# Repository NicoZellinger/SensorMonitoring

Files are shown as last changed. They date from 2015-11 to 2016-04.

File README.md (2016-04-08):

#Universal Data Aquisition Network System

#SensorMonitoring
In this project a system should be developed which is possible to carry out several sensor measurements and to send the values over WLAN to a central system. 
Afterwards in the central system the measuring results should be evaluated and documented for a period. 

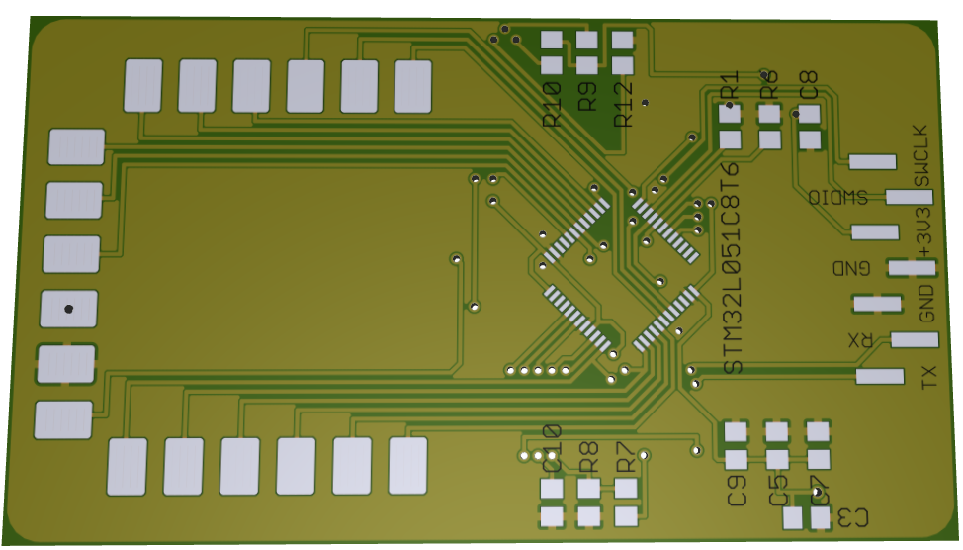
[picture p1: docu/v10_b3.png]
Bottom

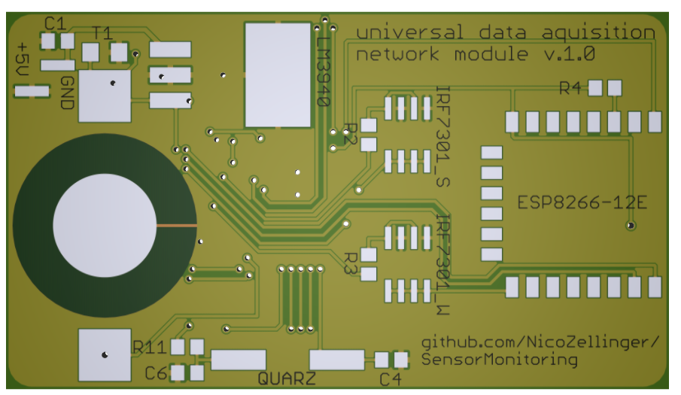
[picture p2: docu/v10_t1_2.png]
top


# Hardware
In the essentials the sensor board is a WLAN module, a microcontroller and any sensor. 
The microcontroller reads the values of the sensor in a configureable frequency and transfers this to the WLAN module. 
The WLAN module sends the values to the central system (Raspberry Pi with Raspbian). 
Afterwards on the central system the measuring results are evaluated and documented. 
Beyond it, the central system administered the sensor boards. 

# Power
So that the sensor boards can be used mobile, the boards are supplied with a 3 volt battery. 
To put off the unloading of the battery as long as possible a "ultra low power" microcontroller from STMicroelectronic is used.
Besides, the controller is moved, as long as he takes up no measurement, into the Sleep mode. 
Above, the WLAN module and the sensor is separated with the help of a FET from the supply voltage (As long as no measurement is made).

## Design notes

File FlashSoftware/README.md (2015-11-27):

## This is the Software to generate the *.hex* file for sensorboard with breakout

## Idea
The software should have a button to load the *.hex* file containing the firmware to flash.  
For every generated firmware there should be an JSON file describing the variables one
can edit in the flash storage.

In the software, one loads the *.hex* file containing the firmware and the JSON file.
With the JSON file the software can present a list of variables the user can edit.  
Then the user can click a *save* button to generate a new *.hex* file with the firmware
and the variables.  
This file can now be flashed.

## UI design
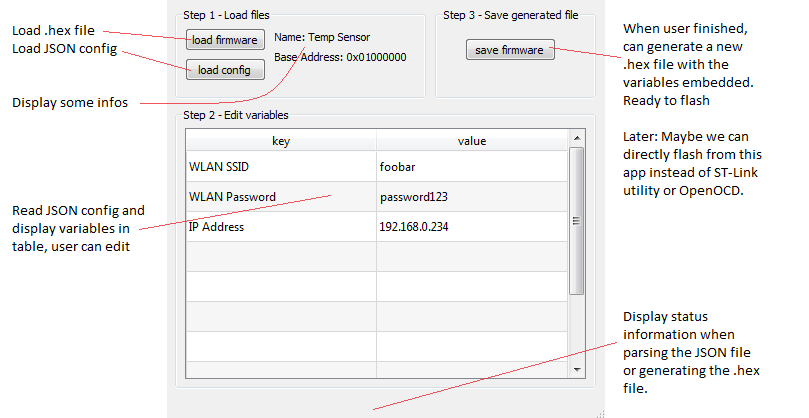
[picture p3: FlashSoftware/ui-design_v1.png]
UI design


### Description
Every variable has a id (the variable name in the firmware), an real name, a type to do typechecking when user edits
and an offset to the base address where this variable is written in the *.hex* file or flash.

Would be nice in the future to generate the JSON file out of the sourcecode directly.  
This could be achieved by marking a section with the variables with code comments.  
The offset can be calculated with the pointer address. The name can be specified by comment and the
type can be obtained out of the code.

## SPEC
Here is an example for the JSON files which describe the variables one can edit:  
[http://www.jsoneditoronline.org/?id=5f7bb21513ac1fcfc43e39b30b590ad5](http://www.jsoneditoronline.org/?id=5f7bb21513ac1fcfc43e39b30b590ad5)

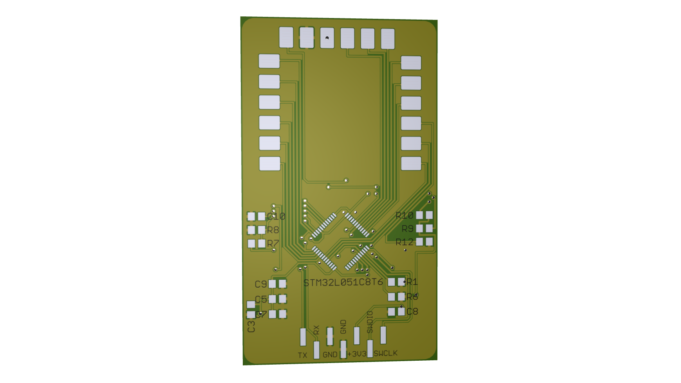
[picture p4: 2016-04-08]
docu/v10_b2.png

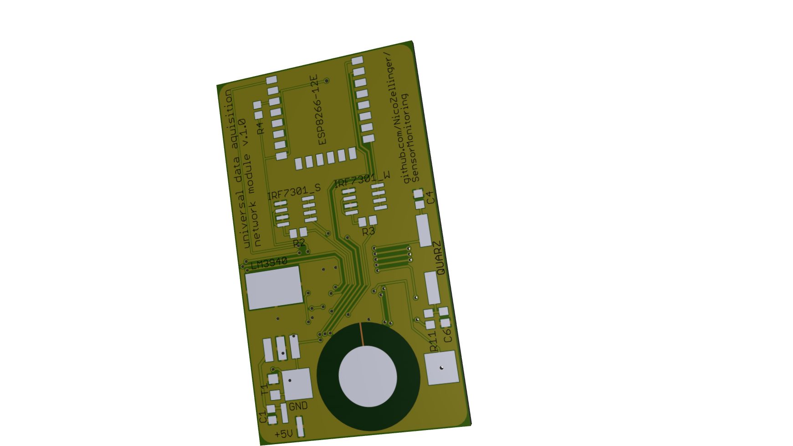
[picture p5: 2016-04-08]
docu/v10_t3.png

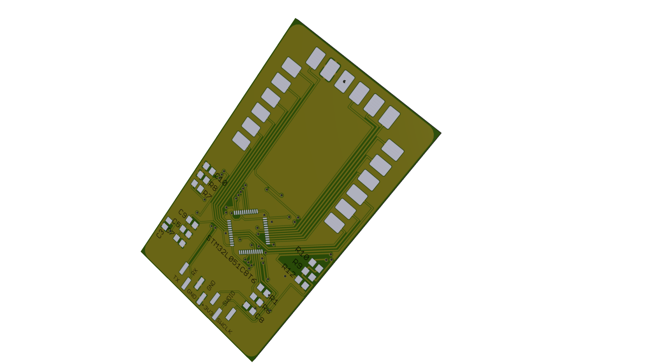
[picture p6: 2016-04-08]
docu/v10_b1.png

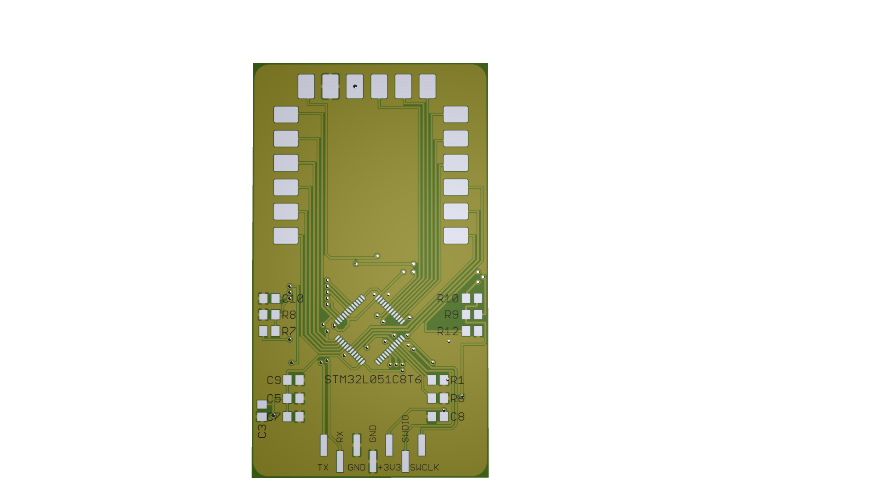
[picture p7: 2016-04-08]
docu/v10_b5.png

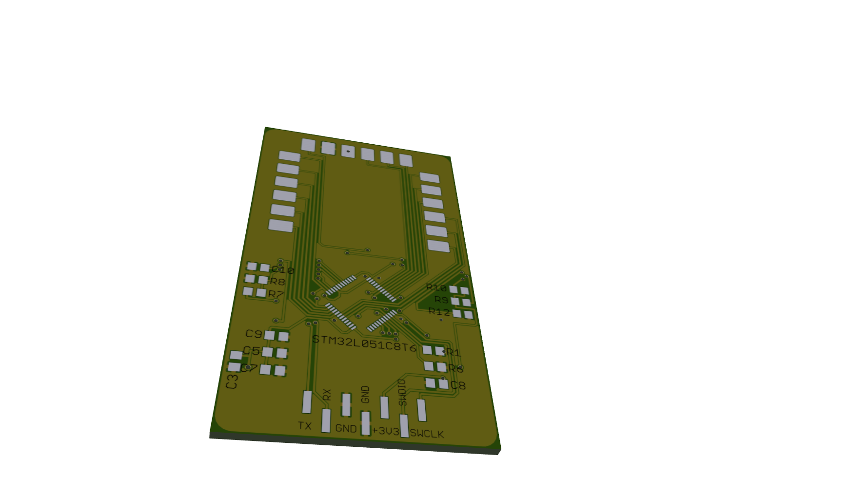
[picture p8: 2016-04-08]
docu/v10_b4.png

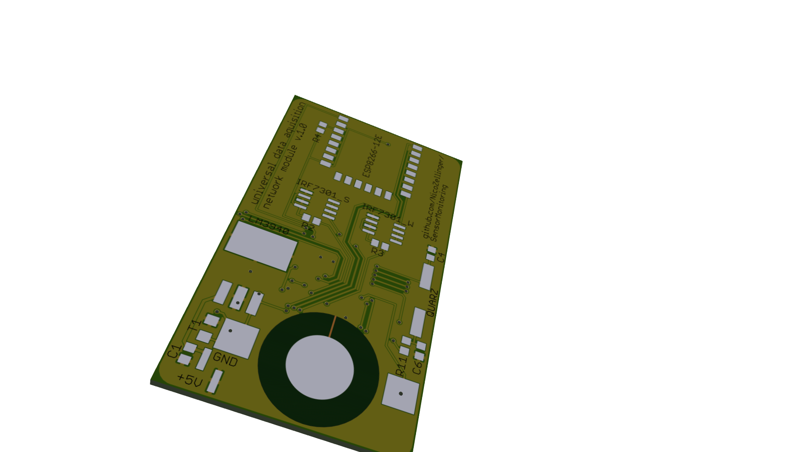
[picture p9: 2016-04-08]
docu/v10_t2.png

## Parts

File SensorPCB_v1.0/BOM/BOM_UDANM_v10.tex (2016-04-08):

\documentclass[a4paper,fontsize=12pt,fleqn]{scrartcl}
\usepackage[ngerman]{babel}
\usepackage[utf8]{inputenc}												
\usepackage[automark]{scrpage2}

\usepackage[hyphens]{url}
\usepackage{hyperref}
\usepackage{amsmath}
\hypersetup{unicode=true,colorlinks=true,urlcolor=black,citecolor=black,linkcolor=black}

\usepackage{caption}
\captionsetup[figure]{skip=10pt}

\usepackage{array}
\usepackage{multirow}
\usepackage{subfigure} 
\usepackage{tabularx}
\newcolumntype{L}[1]{>{\raggedright\arraybackslash}p{#1}}
\newcolumntype{C}[1]{>{\centering\arraybackslash}p{#1}}
\newcolumntype{R}[1]{>{\raggedleft\arraybackslash}p{#1}}

\pagestyle{scrheadings}
\renewcommand*{\sectionmarkformat}{}
\clearscrheadfoot{}
\setkomafont{pagenumber}{\bfseries}
\ohead[]{Bill of Materials}
 \cfoot{\raisebox{-4.5mm}{-{ }\pagemark{ }-}} 
\usepackage{anyfontsize}
\usepackage{geometry}
\geometry{a4paper, top=27mm, left=25mm, right=20mm, bottom=35mm, headsep=10mm, footskip=20mm}
\usepackage{setspace} 
\onehalfspacing

\begin{document}

\pagenumbering{arabic}
\setcounter{page}{1}
%
\input{source/BOM}

\end{document}

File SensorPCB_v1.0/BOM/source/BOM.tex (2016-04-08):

\section*{Bill of Materials}

\begin{table}[h] \centering
    \begin{tabular}{|c|c|c|c|c|}\hline
    \textbf{Name}        &\textbf{Value}    & \textbf{Quantity}	    & \textbf{Package}    & \textbf{Links}\\ \hline
%
     C1    			     & 470n            & 1			            & 0805                & \url{?}\\ \hline
     C3    			     & 10u             & 1			            & 0805                & \url{}\\ \hline
     C4, C6    		     & 20p             & 2			            & 0805                & \url{}\\ \hline
     C5, C7, C8, C10     & 100n            & 1			            & 0805                & \url{}\\ \hline
     C9    			     & 1u              & 1			            & 0805                & \url{}\\ \hline
     ESP8266-12E (WLAN)  & ESP8266-12E     & 1			            & ESP8266-12E         & \url{ebay.de}\\ \hline
     IRF7301\_S/W        & NPN             & 2			            & SO8                 & \url{}\\ \hline
     JP1, PHD (Pinheader)&                 & 9			            & SMD, 2.54 mm        & \url{}\\ \hline
     LM3940    			 & 5V to 3.3V      & 1			            & DDPACK              & \url{}\\ \hline
     QUARZ    			 & 8 MHz           & 1			            & HC49-SMD            & \url{}\\ \hline
     R1, R6    		     & 100k            & 2			            & 0805                & \url{}\\ \hline
     R2, R3    			 & 150             & 2		                & 0805                & \url{}\\ \hline
     R4, R7, R8, R12     & 10k             & 4	                    & 0805                & \url{}\\ \hline
     R9, R10    	     & 1.8k            & 2			            & 0805                & \url{}\\ \hline
     R11  			     & 390             & 1			            & 0805                & \url{}\\ \hline
     STM32L051C8T6       &                 & 1			            & LQFP48              & \url{}\\ \hline
     T1    			     & 33u Tantal      & 1			            & 1206                & \url{}\\ \hline
     KZH\_20SMD (Battery)&                 & 1			            & KZH\_20SMD          & \url{}\\ \hline
 \end{tabular}
 \caption{BOM SensorPCB Version 1.0}
 \label{tab:plat}
\end{table}

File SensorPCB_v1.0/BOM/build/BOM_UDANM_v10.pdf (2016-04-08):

Bill of Materials

## Bill of Materials

Name | Value | Quantity | Package | Links
C1 | 470n | 1 | 0805 | ?
C3 | 10u | 1 | 0805
C4, C6 | 20p | 2 | 0805
C5, C7, C8, C10 | 100n | 1 | 0805
C9 | 1u | 1 | 0805
ESP8266-12E (WLAN) | ESP8266-12E | 1 | ESP8266-12E | ebay.de
IRF7301 S/W | NPN | 2 | SO8
JP1, PHD (Pinheader) | | 9 | SMD, 2.54 mm
LM3940 | 5V to 3.3V | 1 | DDPACK
QUARZ | 8 MHz | 1 | HC49-SMD
R1, R6 | 100k | 2 | 0805
R2, R3 | 150 | 2 | 0805
R4, R7, R8, R12 | 10k | 4 | 0805
R9, R10 | 1.8k | 2 | 0805
R11 | 390 | 1 | 0805
STM32L051C8T6 | | 1 | LQFP48
T1 | 33u Tantal | 1 | 1206
KZH 20SMD (Battery) | | 1 | KZH 20SMD

Tabelle 1: BOM SensorPCB Version 1.0

- 1 -

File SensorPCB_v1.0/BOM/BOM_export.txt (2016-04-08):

Partlist

Exported from SensorPCB.sch at 12.12.15 22:51

EAGLE Version 7.4.0 Copyright (c) 1988-2015 CadSoft

Assembly variant: 

Part          Value          Device                    Package               Library               Sheet

BREAKOUTBOARD BREAKOUT_FP_V1 BREAKOUT_FP_V1            BREAKOUT_FOOTPRINT_V1 breakout_base         1
C1            470n           C-EUC0805                 C0805                 rcl                   1
C3            10u            C-EUC0805                 C0805                 rcl                   1
C4            20p            C-EUC0805                 C0805                 rcl                   1
C5            100n           C-EUC0805                 C0805                 rcl                   1
C6            20p            C-EUC0805                 C0805                 rcl                   1
C7            100n           C-EUC0805                 C0805                 rcl                   1
C8            100n           C-EUC0805                 C0805                 rcl                   1
C9            1u             C-EUC0805                 C0805                 rcl                   1
C10           100n           C-EUC0805                 C0805                 rcl                   1
ESP8266-12E                  ESP8266-12EESP8266-ESP12E ESP8266-ESP12E        ESP8266-ESP12E        1
IRF7301_S     IRF7301        IRF7301                   IRF7301_PACK_SO8      irf7301_symb          1
IRF7301_W     IRF7301        IRF7301                   IRF7301_PACK_SO8      irf7301_symb          1
JP1                          PINHD-1X2_2.54-SMD        1X02SMD               pinhead               1
LM3940        LM3940         LM3940                    LM3940_PACK           lm3940                1
PHD                          PINHD-1X7_2.54-SMD        1X07SMD               pinhead               1
QUARZ         QUARZ_HC49-SMD QUARZ_HC49-SMD            HC49-SMD              quarz_hc49_smd        1
R1            100k           R-EU_R0805                R0805                 rcl                   1
R2            150            R-EU_R0805                R0805                 rcl                   1
R3            150            R-EU_R0805                R0805                 rcl                   1
R4            10k            R-EU_R0805                R0805                 rcl                   1
R6            100k           R-EU_R0805                R0805                 rcl                   1
R7            10k            R-EU_R0805                R0805                 rcl                   1
R8            10k            R-EU_R0805                R0805                 rcl                   1
R9            1k8            R-EU_R0805                R0805                 rcl                   1
R10           1k8            R-EU_R0805                R0805                 rcl                   1
R11           390            R-EU_R0805                R0805                 rcl                   1
R12           10k            R-EU_R0805                R0805                 rcl                   1
STM32L051C8T6 STM32L051X6/8  STM32L051X6/8             LQFP48                STM32L051x6_LQFP48XXL 1
T1            33u            CAP_TANTAL_1206           1206                  CAP_TANTAL_1206       1
U$1           KZH_20SMD      KZH_20SMD                 KHZ_20SMD             KZH_20SMD             1

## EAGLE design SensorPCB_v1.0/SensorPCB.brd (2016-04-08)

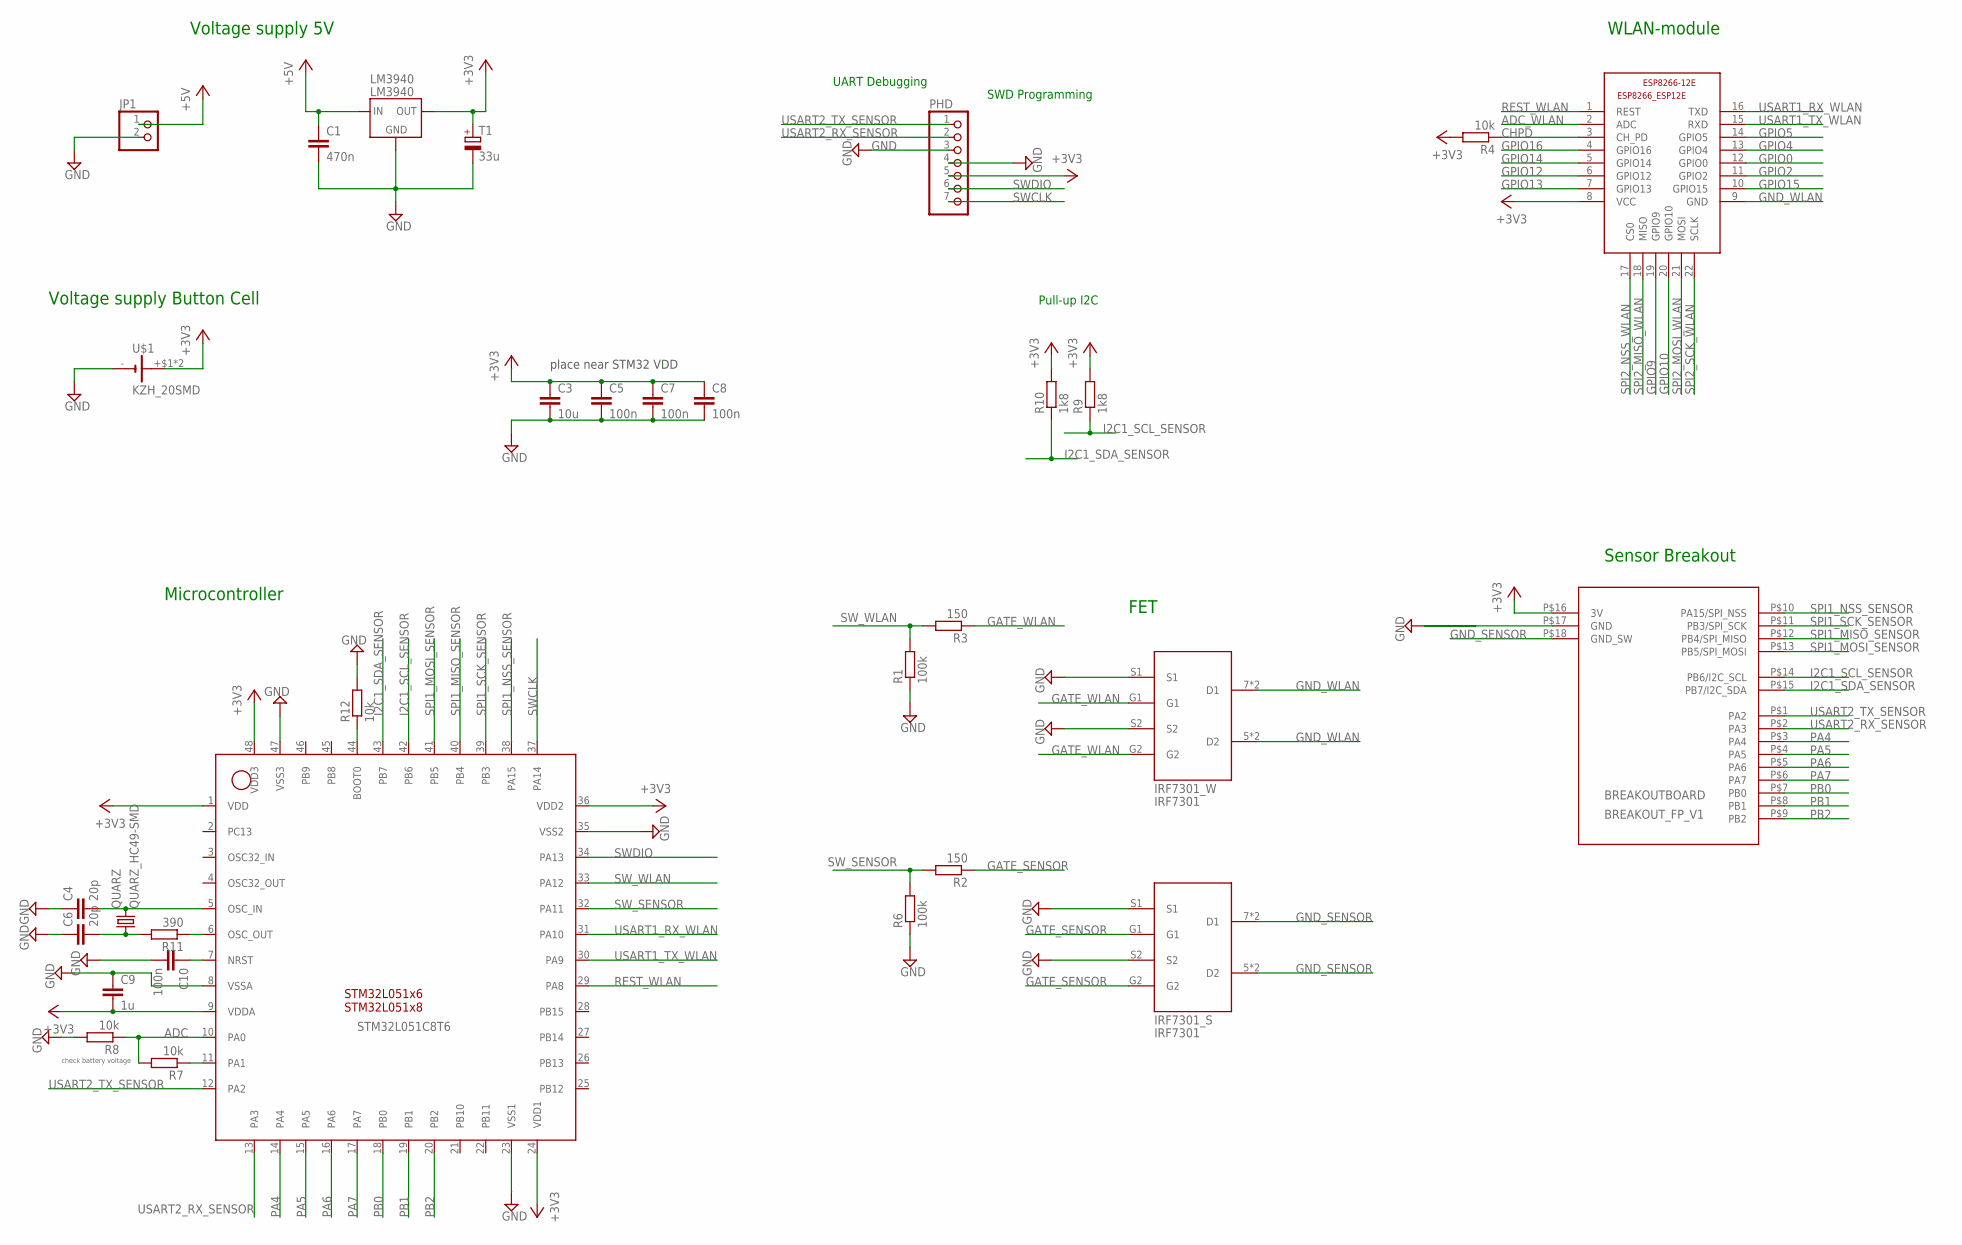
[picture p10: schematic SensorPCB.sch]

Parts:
BREAKOUTBOARD: BREAKOUT_FP_V1; BREAKOUT_FOOTPRINT_V1
C1: 470n; C0805
C3: 10u; C0805
C4, C6: 20p; C0805
C5, C7, C8, C10: 100n; C0805
C9: 1u; C0805
ESP8266-12E: ESP8266-12EESP8266-ESP12E; ESP8266-ESP12E
IRF7301_S, IRF7301_W: IRF7301; IRF7301_PACK_SO8
JP1: PINHD-1X2_2.54-SMD; 1X02SMD
LM3940: LM3940; LM3940_PACK
PHD: PINHD-1X7_2.54-SMD; 1X07SMD
QUARZ: QUARZ_HC49-SMD; HC49-SMD
R1, R6: 100k; R0805
R2, R3: 150; R0805
R4, R7, R8, R12: 10k; R0805
R9, R10: 1k8; R0805
R11: 390; R0805
STM32L051C8T6: STM32L051X6/8; LQFP48
T1: 33u; 1206
U$1: KZH_20SMD; KHZ_20SMD

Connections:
+3V3: BREAKOUTBOARD.P$16 (3V), C3.1, C5.1, C7.1, C8.1, C9.2, ESP8266-12E.8 (VCC), LM3940.3 (OUT), PHD.5, R4.2, R9.2, R10.2, STM32L051C8T6.1 (VDD), STM32L051C8T6.9 (VDDA), STM32L051C8T6.24 (VDD1), STM32L051C8T6.36 (VDD2), STM32L051C8T6.48 (VDD3), T1.1 (+), U$1.+$1 (+), U$1.+$2 (+)
+5V: C1.1, JP1.1, LM3940.1 (IN)
ADC: R7.2, R8.1, STM32L051C8T6.10 (PA0)
ADC_WLAN: ESP8266-12E.2 (ADC)
CHPD: ESP8266-12E.3 (CH_PD), R4.1
GATE_SENSOR: IRF7301_S.G1, IRF7301_S.G2, R2.1
GATE_WLAN: IRF7301_W.G1, IRF7301_W.G2, R3.1
GND: BREAKOUTBOARD.P$17 (GND), C1.2, C3.2, C4.1, C5.2, C6.1, C7.2, C8.2, C9.1, C10.2, IRF7301_S.S1, IRF7301_S.S2, IRF7301_W.S1, IRF7301_W.S2, JP1.2, LM3940.2 (GND), LM3940.4 (GND), PHD.3, PHD.4, R1.1, R6.1, R8.2, R12.2, STM32L051C8T6.8 (VSSA), STM32L051C8T6.23 (VSS1), STM32L051C8T6.35 (VSS2), STM32L051C8T6.47 (VSS3), T1.2 (-), U$1.-
GND_SENSOR: BREAKOUTBOARD.P$18 (GND_SW), IRF7301_S.5 (D2), IRF7301_S.7 (D1), IRF7301_S.D1, IRF7301_S.D2
GND_WLAN: ESP8266-12E.9 (GND), IRF7301_W.5 (D2), IRF7301_W.7 (D1), IRF7301_W.D1, IRF7301_W.D2
GPIO0: ESP8266-12E.12 (GPIO0)
GPIO2: ESP8266-12E.11 (GPIO2)
GPIO4: ESP8266-12E.13 (GPIO4)
GPIO5: ESP8266-12E.14 (GPIO5)
GPIO9: ESP8266-12E.19 (GPIO9)
GPIO10: ESP8266-12E.20 (GPIO10)
GPIO12: ESP8266-12E.6 (GPIO12)
GPIO13: ESP8266-12E.7 (GPIO13)
GPIO14: ESP8266-12E.5 (GPIO14)
GPIO15: ESP8266-12E.10 (GPIO15)
GPIO16: ESP8266-12E.4 (GPIO16)
I2C1_SCL_SENSOR: BREAKOUTBOARD.P$14 (PB6/I2C_SCL), R9.1, STM32L051C8T6.42 (PB6)
I2C1_SDA_SENSOR: BREAKOUTBOARD.P$15 (PB7/I2C_SDA), R10.1, STM32L051C8T6.43 (PB7)
unnamed: R7.1, STM32L051C8T6.11 (PA1)
unnamed: C6.2, QUARZ.1, R11.2
unnamed: C10.1, STM32L051C8T6.7 (NRST)
unnamed: R12.1, STM32L051C8T6.44 (BOOT0)
OSC_IN: C4.2, QUARZ.2, STM32L051C8T6.5 (OSC_IN)
OSC_OUT: R11.1, STM32L051C8T6.6 (OSC_OUT)
PA4: BREAKOUTBOARD.P$3 (PA4), STM32L051C8T6.14 (PA4)
PA5: BREAKOUTBOARD.P$4 (PA5), STM32L051C8T6.15 (PA5)
PA6: BREAKOUTBOARD.P$5 (PA6), STM32L051C8T6.16 (PA6)
PA7: BREAKOUTBOARD.P$6 (PA7), STM32L051C8T6.17 (PA7)
PB0: BREAKOUTBOARD.P$7 (PB0), STM32L051C8T6.18 (PB0)
PB1: BREAKOUTBOARD.P$8 (PB1), STM32L051C8T6.19 (PB1)
PB2: BREAKOUTBOARD.P$9 (PB2), STM32L051C8T6.20 (PB2)
REST_WLAN: ESP8266-12E.1 (REST), STM32L051C8T6.29 (PA8)
SPI1_MISO_SENSOR: BREAKOUTBOARD.P$12 (PB4/SPI_MISO), STM32L051C8T6.40 (PB4)
SPI1_MOSI_SENSOR: BREAKOUTBOARD.P$13 (PB5/SPI_MOSI), STM32L051C8T6.41 (PB5)
SPI1_NSS_SENSOR: BREAKOUTBOARD.P$10 (PA15/SPI_NSS), STM32L051C8T6.38 (PA15)
SPI1_SCK_SENSOR: BREAKOUTBOARD.P$11 (PB3/SPI_SCK), STM32L051C8T6.39 (PB3)
SPI2_MISO_WLAN: ESP8266-12E.18 (MISO)
SPI2_MOSI_WLAN: ESP8266-12E.21 (MOSI)
SPI2_NSS_WLAN: ESP8266-12E.17 (CS0)
SPI2_SCK_WLAN: ESP8266-12E.22 (SCLK)
SWCLK: PHD.7, STM32L051C8T6.37 (PA14)
SWDIO: PHD.6, STM32L051C8T6.34 (PA13)
SW_SENSOR: R2.2, R6.2, STM32L051C8T6.32 (PA11)
SW_WLAN: R1.2, R3.2, STM32L051C8T6.33 (PA12)
USART1_RX_WLAN: ESP8266-12E.16 (TXD), STM32L051C8T6.31 (PA10)
USART1_TX_WLAN: ESP8266-12E.15 (RXD), STM32L051C8T6.30 (PA9)
USART2_RX_SENSOR: BREAKOUTBOARD.P$2 (PA3), PHD.2, STM32L051C8T6.13 (PA3)
USART2_TX_SENSOR: BREAKOUTBOARD.P$1 (PA2), PHD.1, STM32L051C8T6.12 (PA2)

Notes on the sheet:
Voltage supply 5V
WLAN-module
Voltage supply Button Cell
Microcontroller
FET
Sensor Breakout
UART Debugging
SWD Programming
place near STM32 VDD
check battery voltage
Pull-up I2C

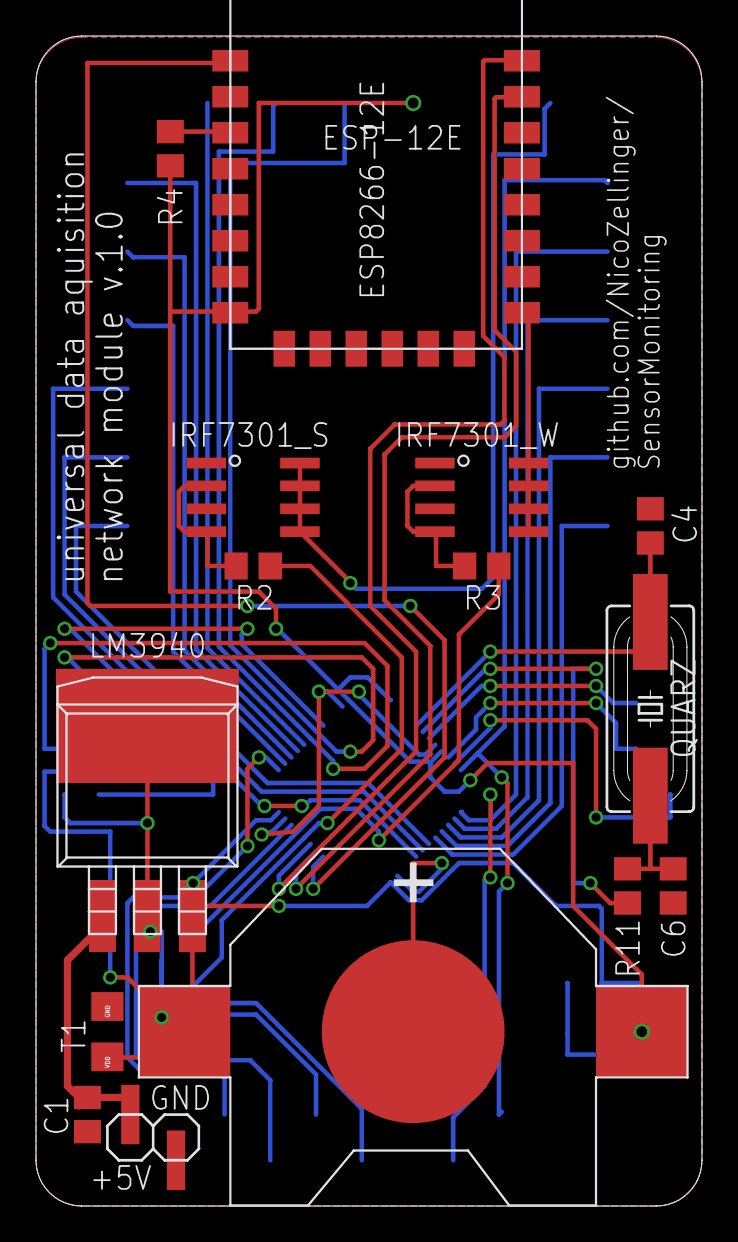
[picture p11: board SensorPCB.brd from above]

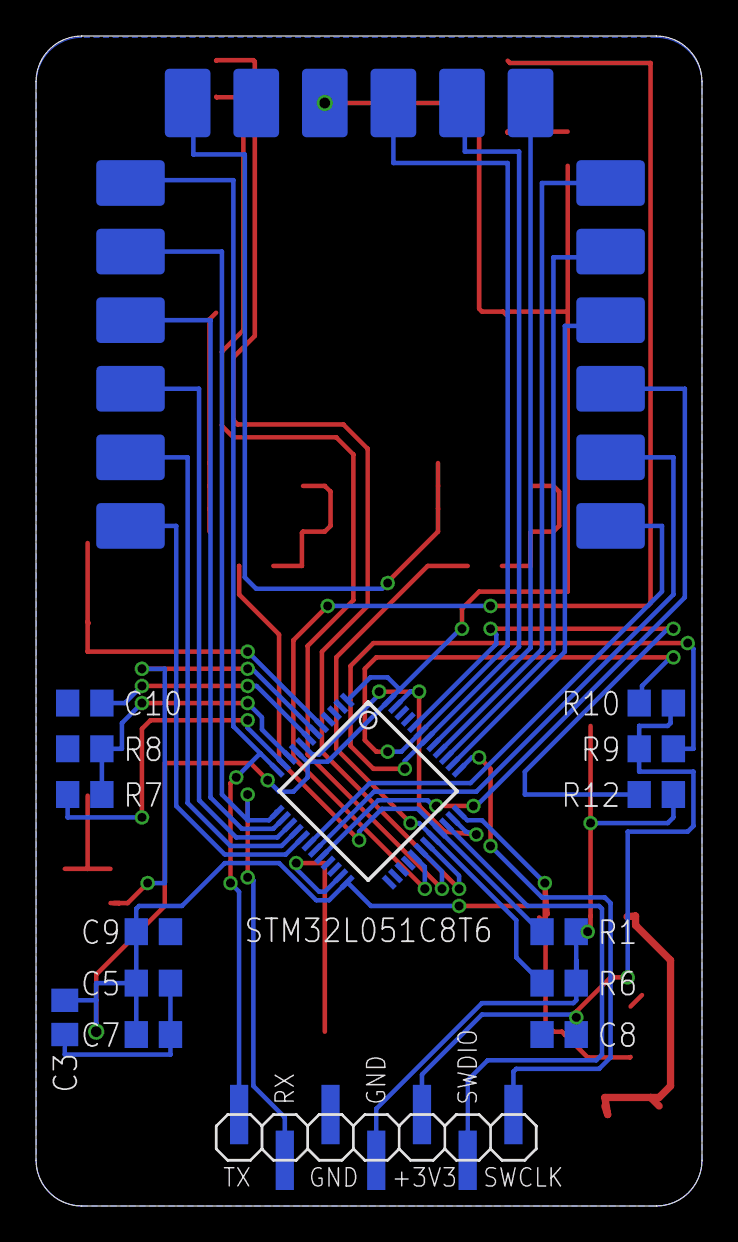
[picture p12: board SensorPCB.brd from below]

Board: 2 copper layers, 37.0 x 65.0 mm, 31 parts (16 on the bottom side), 37 nets.

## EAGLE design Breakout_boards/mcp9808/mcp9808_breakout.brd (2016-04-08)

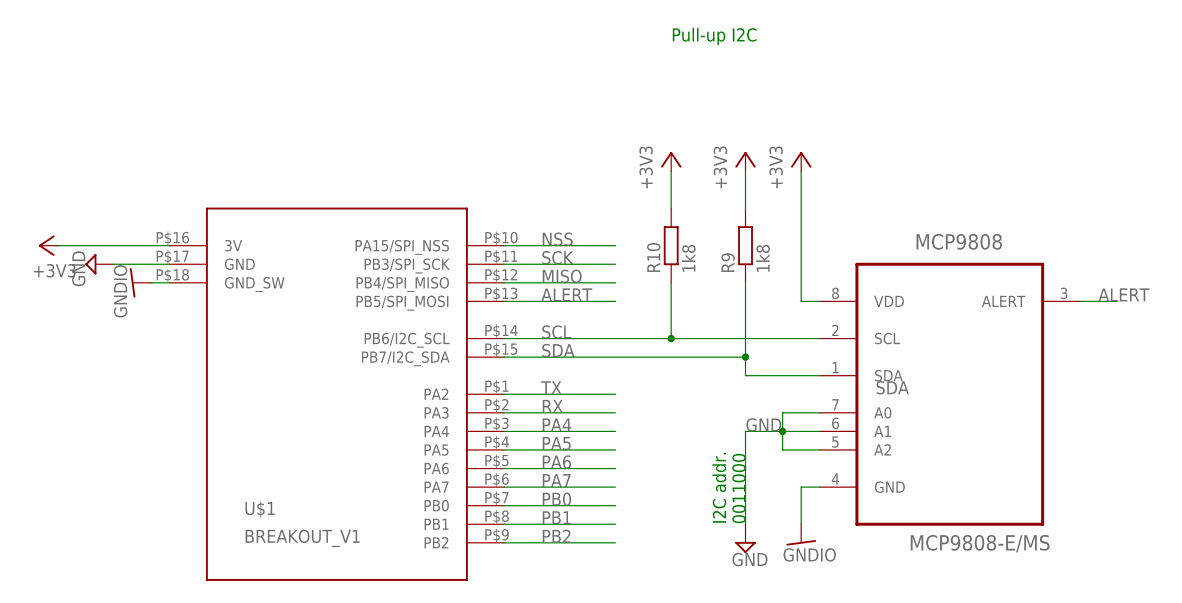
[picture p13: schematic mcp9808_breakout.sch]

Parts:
MCP9808: MCP9808-E/MS; SOP65P490X110-8N
R9, R10: 1k8; R0805
U$1: BREAKOUT_V1

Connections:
+3V3: MCP9808.8 (VDD), R9.2, R10.2, U$1.P$16 (3V)
ALERT: MCP9808.3 (ALERT), U$1.P$13 (PB5/SPI_MOSI)
GND: MCP9808.5 (A2), MCP9808.6 (A1), MCP9808.7 (A0), U$1.P$17 (GND)
GNDIO: MCP9808.4 (GND), U$1.P$18 (GND_SW)
MISO: U$1.P$12 (PB4/SPI_MISO)
NSS: U$1.P$10 (PA15/SPI_NSS)
PA4: U$1.P$3 (PA4)
PA5: U$1.P$4 (PA5)
PA6: U$1.P$5 (PA6)
PA7: U$1.P$6 (PA7)
PB0: U$1.P$7 (PB0)
PB1: U$1.P$8 (PB1)
PB2: U$1.P$9 (PB2)
RX: U$1.P$2 (PA3)
SCK: U$1.P$11 (PB3/SPI_SCK)
SCL: MCP9808.2 (SCL), R10.1, U$1.P$14 (PB6/I2C_SCL)
SDA: MCP9808.1 (SDA), R9.1, U$1.P$15 (PB7/I2C_SDA)
TX: U$1.P$1 (PA2)

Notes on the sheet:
I2C addr. 0011000
Pull-up I2C

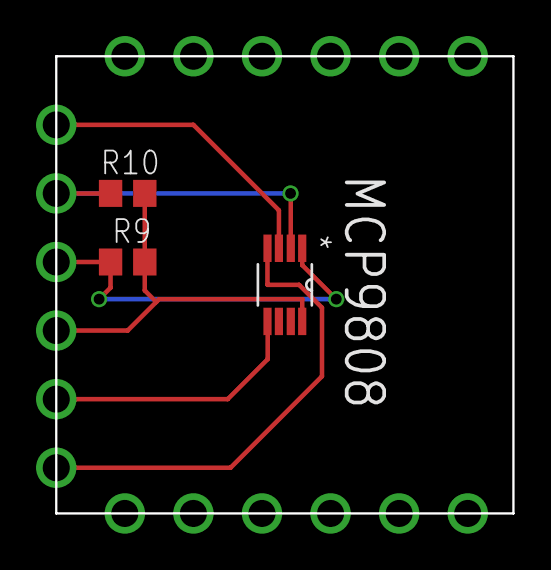
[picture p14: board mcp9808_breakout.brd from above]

Board: 2 copper layers, 25.4 x 25.4 mm, 4 parts (0 on the bottom side), 6 nets.

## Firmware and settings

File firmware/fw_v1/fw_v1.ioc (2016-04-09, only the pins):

Mcu.UserName=STM32L051C8Tx
PA0.Signal=ADC_IN0
PA1.Signal=GPIO_Output
PA10.Signal=USART1_RX
PA11.Signal=GPIO_Output
PA12.Signal=GPIO_Output
PA13.Signal=SYS_SWDIO
PA14.Signal=SYS_SWCLK
PA15.Signal=SPI1_NSS
PA2.Signal=USART2_TX
PA3.Signal=USART2_RX
PA8.Signal=GPIO_Output
PA9.Signal=USART1_TX
PB3.Signal=SPI1_SCK
PB4.Signal=SPI1_MISO
PB5.Signal=SPI1_MOSI
PB6.Signal=I2C1_SCL
PB7.Signal=I2C1_SDA
PH0-OSC_IN.Signal=RCC_OSC_IN
PH1-OSC_OUT.Signal=RCC_OSC_OUT

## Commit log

2015-11-18 SensorPCB: voltage regulator footprint + wlan modul
    [EHMOS.brd]
2015-11-18 SensorPCB: FET
    [SensorPCB.brd, SensorPCB.sch]
2015-11-20 SensorPCB: change FET + change WLAN Footprint + add MCU
    [SensorPCB.brd]
2015-11-21 add quartz crystal and change mcu symbol
    [SensorPCB.brd, SensorPCB.sch]
2015-11-23 update Schematic
    [SensorPCB.brd]
2015-11-23 change FET circuit and STM32 decups
    [SensorPCB.brd]
2015-11-23 add FET pull down resistor
    [SensorPCB.brd, SensorPCB.sch]
2015-11-24 Schematic update
    [SensorPCB.brd, SensorPCB.sch]
2015-11-24 fettes update mit Breakout board
    [SensorPCB.brd, SensorPCB.sch, SensorTemp.brd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]
2015-11-25 Add default Sensor + Add UART
    [SensorPCB.brd, SensorPCB.sch]
2015-11-26 change C and R footprint from 1206 to 0805
    [SensorPCB.brd, SensorPCB.sch]
2015-11-27 add first sensor breakout-7board
    [SensorPCB.brd, SensorPCB.sch, pinheader_breakout.brd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]
2015-11-27 Pinheader-Breakout: add Name of wires (tName layer)
    [pinheader_breakout.brd]
2015-11-27 change part-name
    [SensorPCB.brd, SensorPCB.sch]
2015-11-28 add battery
2015-11-28 some updates + add second gnd-pad for voltage regulator
    [SensorPCB.brd, SensorPCB.sch]
2015-11-28 change STM32 footprint (tstop tcream)
    [SensorPCB.brd, SensorPCB.sch]
2015-11-28 i2c pull up
    [SensorPCB.brd, SensorPCB.sch]
2015-11-28 prepare layout
    [SensorPCB.brd, SensorPCB.sch]
2015-11-28 some updates
    [SensorPCB.brd, SensorPCB.sch]
2015-11-29 start routing
    [SensorPCB.brd]
2015-11-29 routing layout beautiful but maybe not accurate
    [SensorPCB.brd]
2015-11-29 update layout
    [SensorPCB.brd]
2015-11-30 remote top-wires and vias from tstop layer (battery)
    [SensorPCB.brd]
2015-11-30 layout update
    [SensorPCB.brd]
2015-12-01 routed all signal wires, 3v and GND is absent
    [SensorPCB.brd, SensorPCB.sch]
2015-12-01 routed all signal wires, 3v and GND are absent
    [SensorPCB.brd, SensorPCB.sch]
2015-12-01 3v almost ready
    [SensorPCB.brd]
2015-12-01 routed all 3v wires
    [SensorPCB.brd]
2015-12-03 start new board version
    [SensorPCB.brd, SensorPCB.sch]
2015-12-04 some changes
    [SensorPCB.brd]
2015-12-05 delet temp sensor + route all signal wires
    [SensorPCB.brd, SensorPCB.sch]
2015-12-05 routed +3v
    [SensorPCB.brd]
2015-12-06 add GND
    [SensorPCB.brd]
2015-12-06 edit tname and bname
    [SensorPCB.brd, SensorPCB.sch]
2015-12-08 closed #1
    [SensorPCB.brd, SensorPCB.sch]
2015-12-08 closed #3
    [SensorPCB.brd, SensorPCB.sch]
2015-12-10 some last improvements to get ready for version 1.0
    [SensorPCB.GBL, SensorPCB.GBO, SensorPCB.GBP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]
2015-12-10 asynchron pinheader-breakout + generate gerber data
    [pinheader_breakout.GBL, pinheader_breakout.GBO, pinheader_breakout.GBP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]
2015-12-11 update breakout pinheader
    [pinheader_breakout.GBL, pinheader_breakout.GBO, pinheader_breakout.GBP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]
2015-12-11 update mcp breakout
    [pinheader_breakout.GBL, pinheader_breakout.GBO, pinheader_breakout.GBP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]
2015-12-12 create gerber data + order sensorPCB, pinhead & mcp breakout
    [SensorPCB.GBL, SensorPCB.GBO, SensorPCB.GBP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]
